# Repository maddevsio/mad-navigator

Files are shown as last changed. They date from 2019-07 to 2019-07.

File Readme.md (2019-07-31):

# Mad navigator

## Description

Mad navigator is simple compass-like device shows direction to predefined geo point.
This repository contains firmware source code and schematics for device. 



## Technologies and modules

- Microcontroller [STM32F100RBT6](https://www.st.com/content/ccc/resource/technical/document/reference_manual/a2/2d/02/4b/78/57/41/a3/CD00246267.pdf/files/CD00246267.pdf/jcr:content/translations/en.C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)
- LCD display [Nokia 5110](https://www.sparkfun.com/datasheets/LCD/Monochrome/Nokia5110.pdf)
- Accelerometer + gyroscope [MPU6050](https://store.invensense.com/datasheets/invensense/MPU-6050_DataSheet_V3%204.pdf)
- GPS receiver [Neo-6M](https://www.u-blox.com/sites/default/files/products/documents/NEO-6_DataSheet_%28GPS.G6-HW-09005%29.pdf)
- Magnetometer [QMC5883L](https://nettigo.pl/attachments/440)

## Prerequisites

- make
- arm-none-eabi-* (gcc, gdb, ar etc.)
- st-link utils

## Folder structure

root: Makefile, qtcreator project file (not neccessary to use it), LinkerScript

inc: All include files

src: All firmware source files

startup: Standard startup code

kicad_schema: Schematic

## How to run/debug

### RUN

Just use `make clean all program` . Make sure that your device connected via USB and you have all needed permissions.
You don't need to `make clean` every time. 

### DEBUG

1. `make clean all program`
2. run `st-util`. It will launch gdb server on localhost:4242. 
3. use arm-none-eabi-gdb

## Extended documentation

!TODO add link to medium

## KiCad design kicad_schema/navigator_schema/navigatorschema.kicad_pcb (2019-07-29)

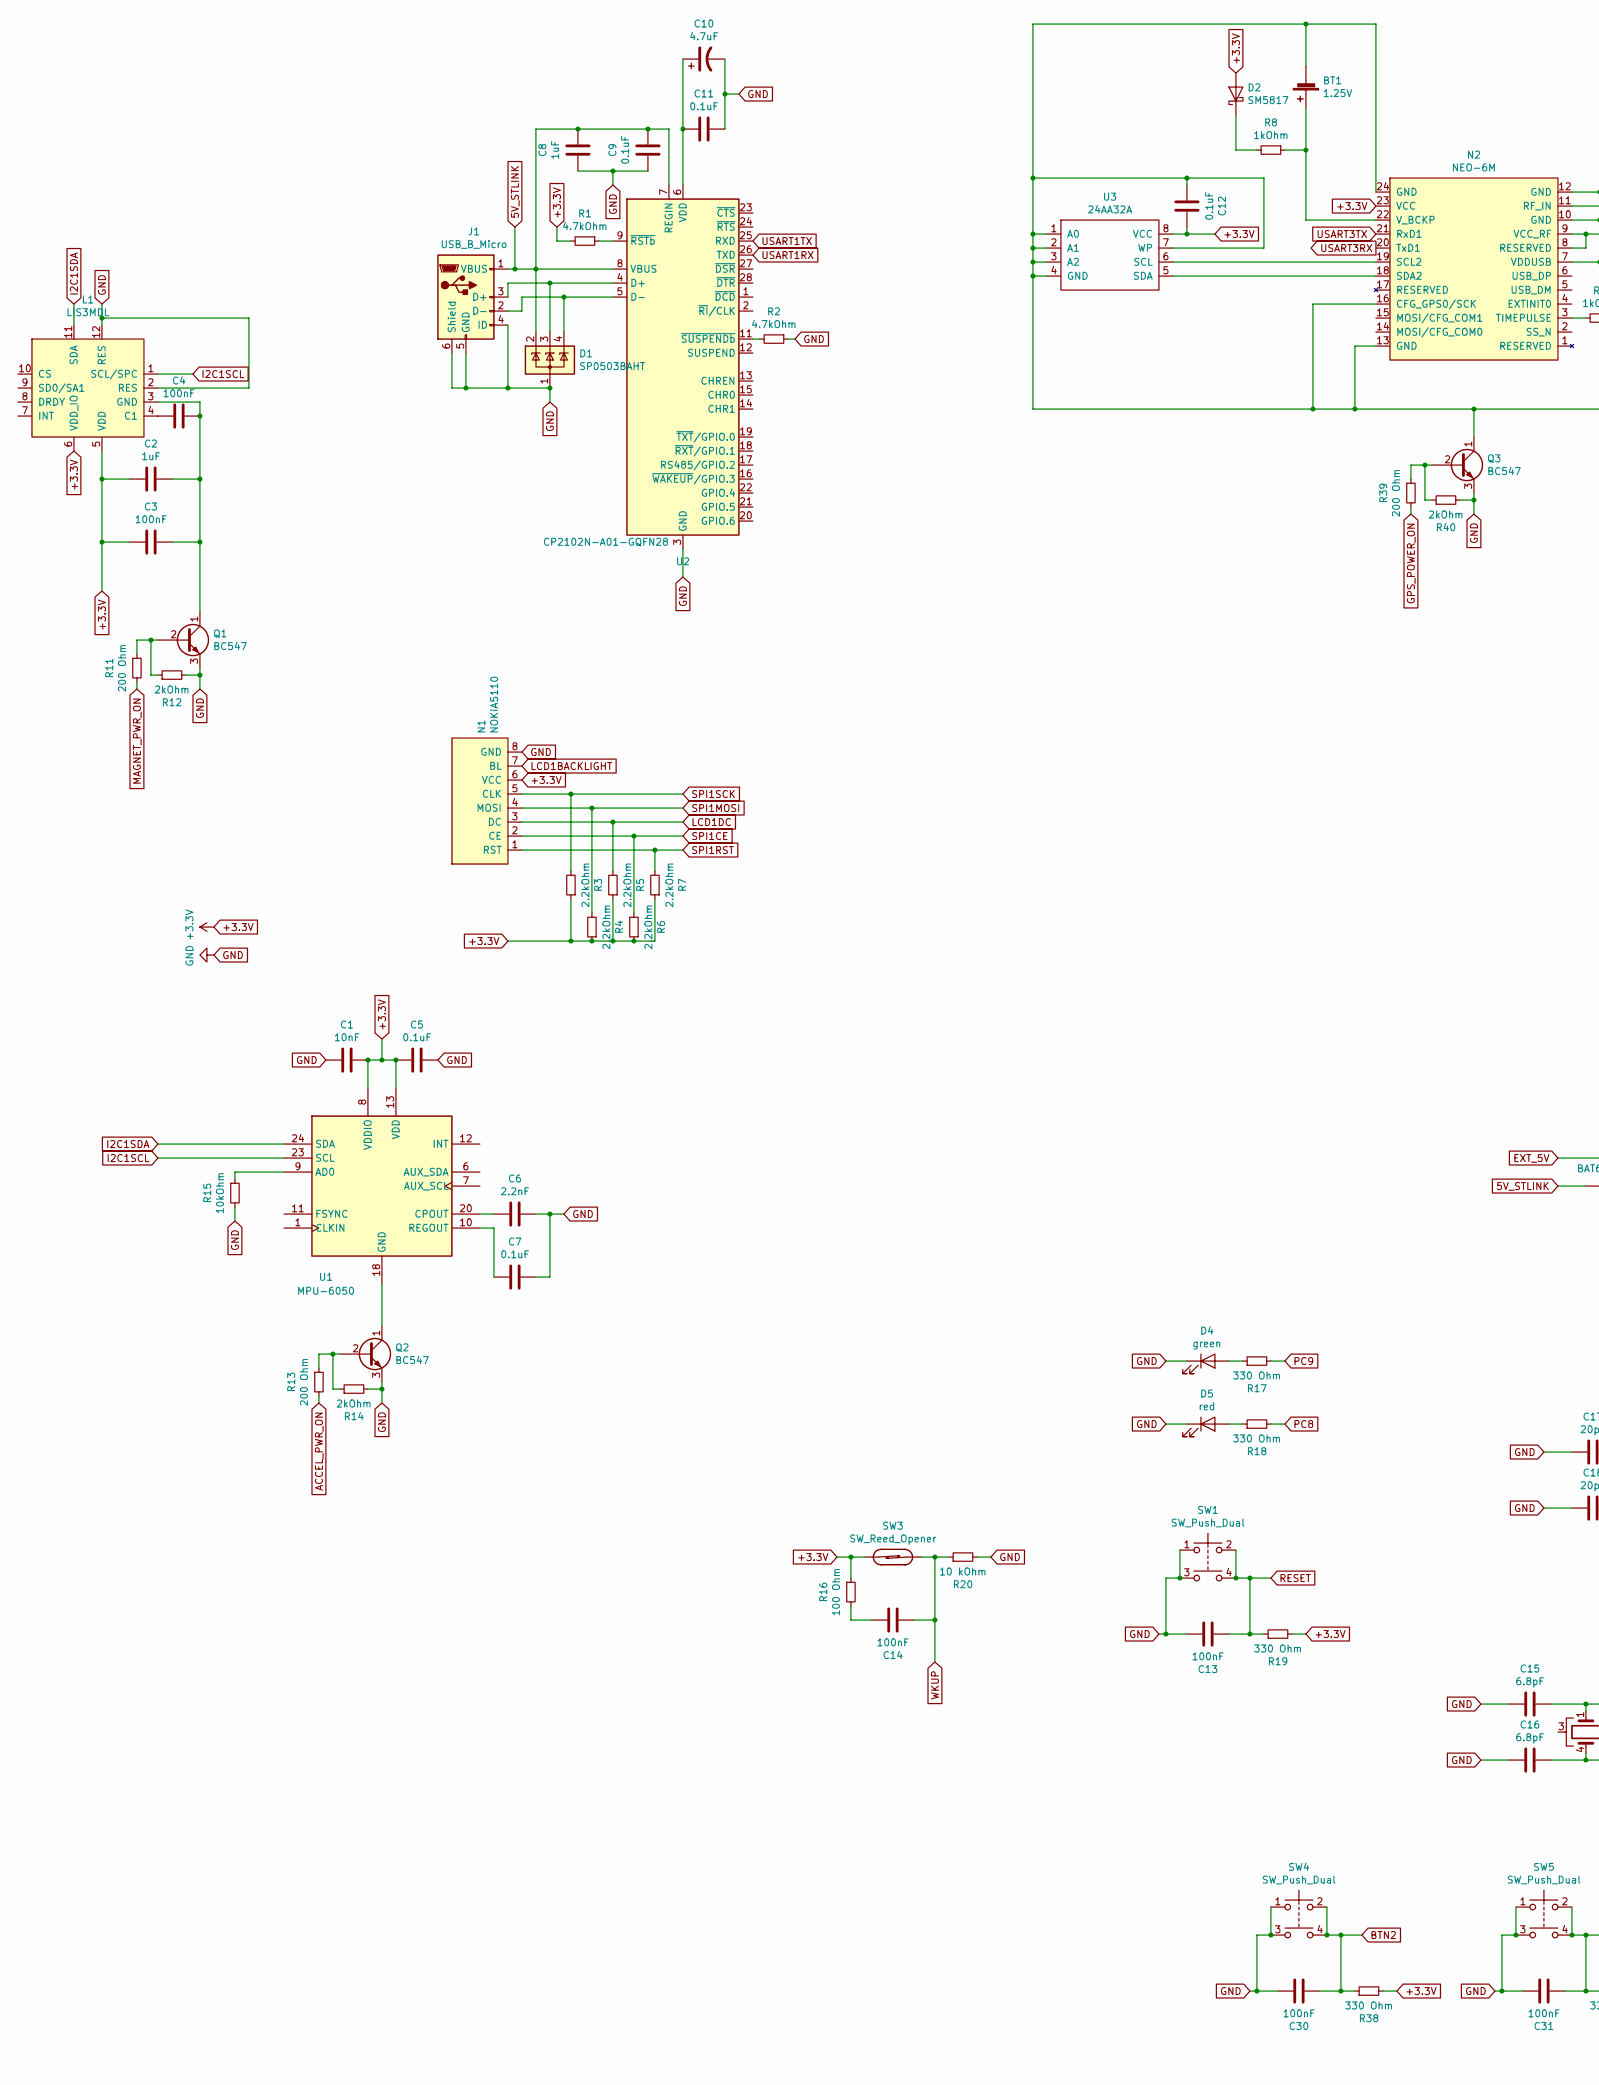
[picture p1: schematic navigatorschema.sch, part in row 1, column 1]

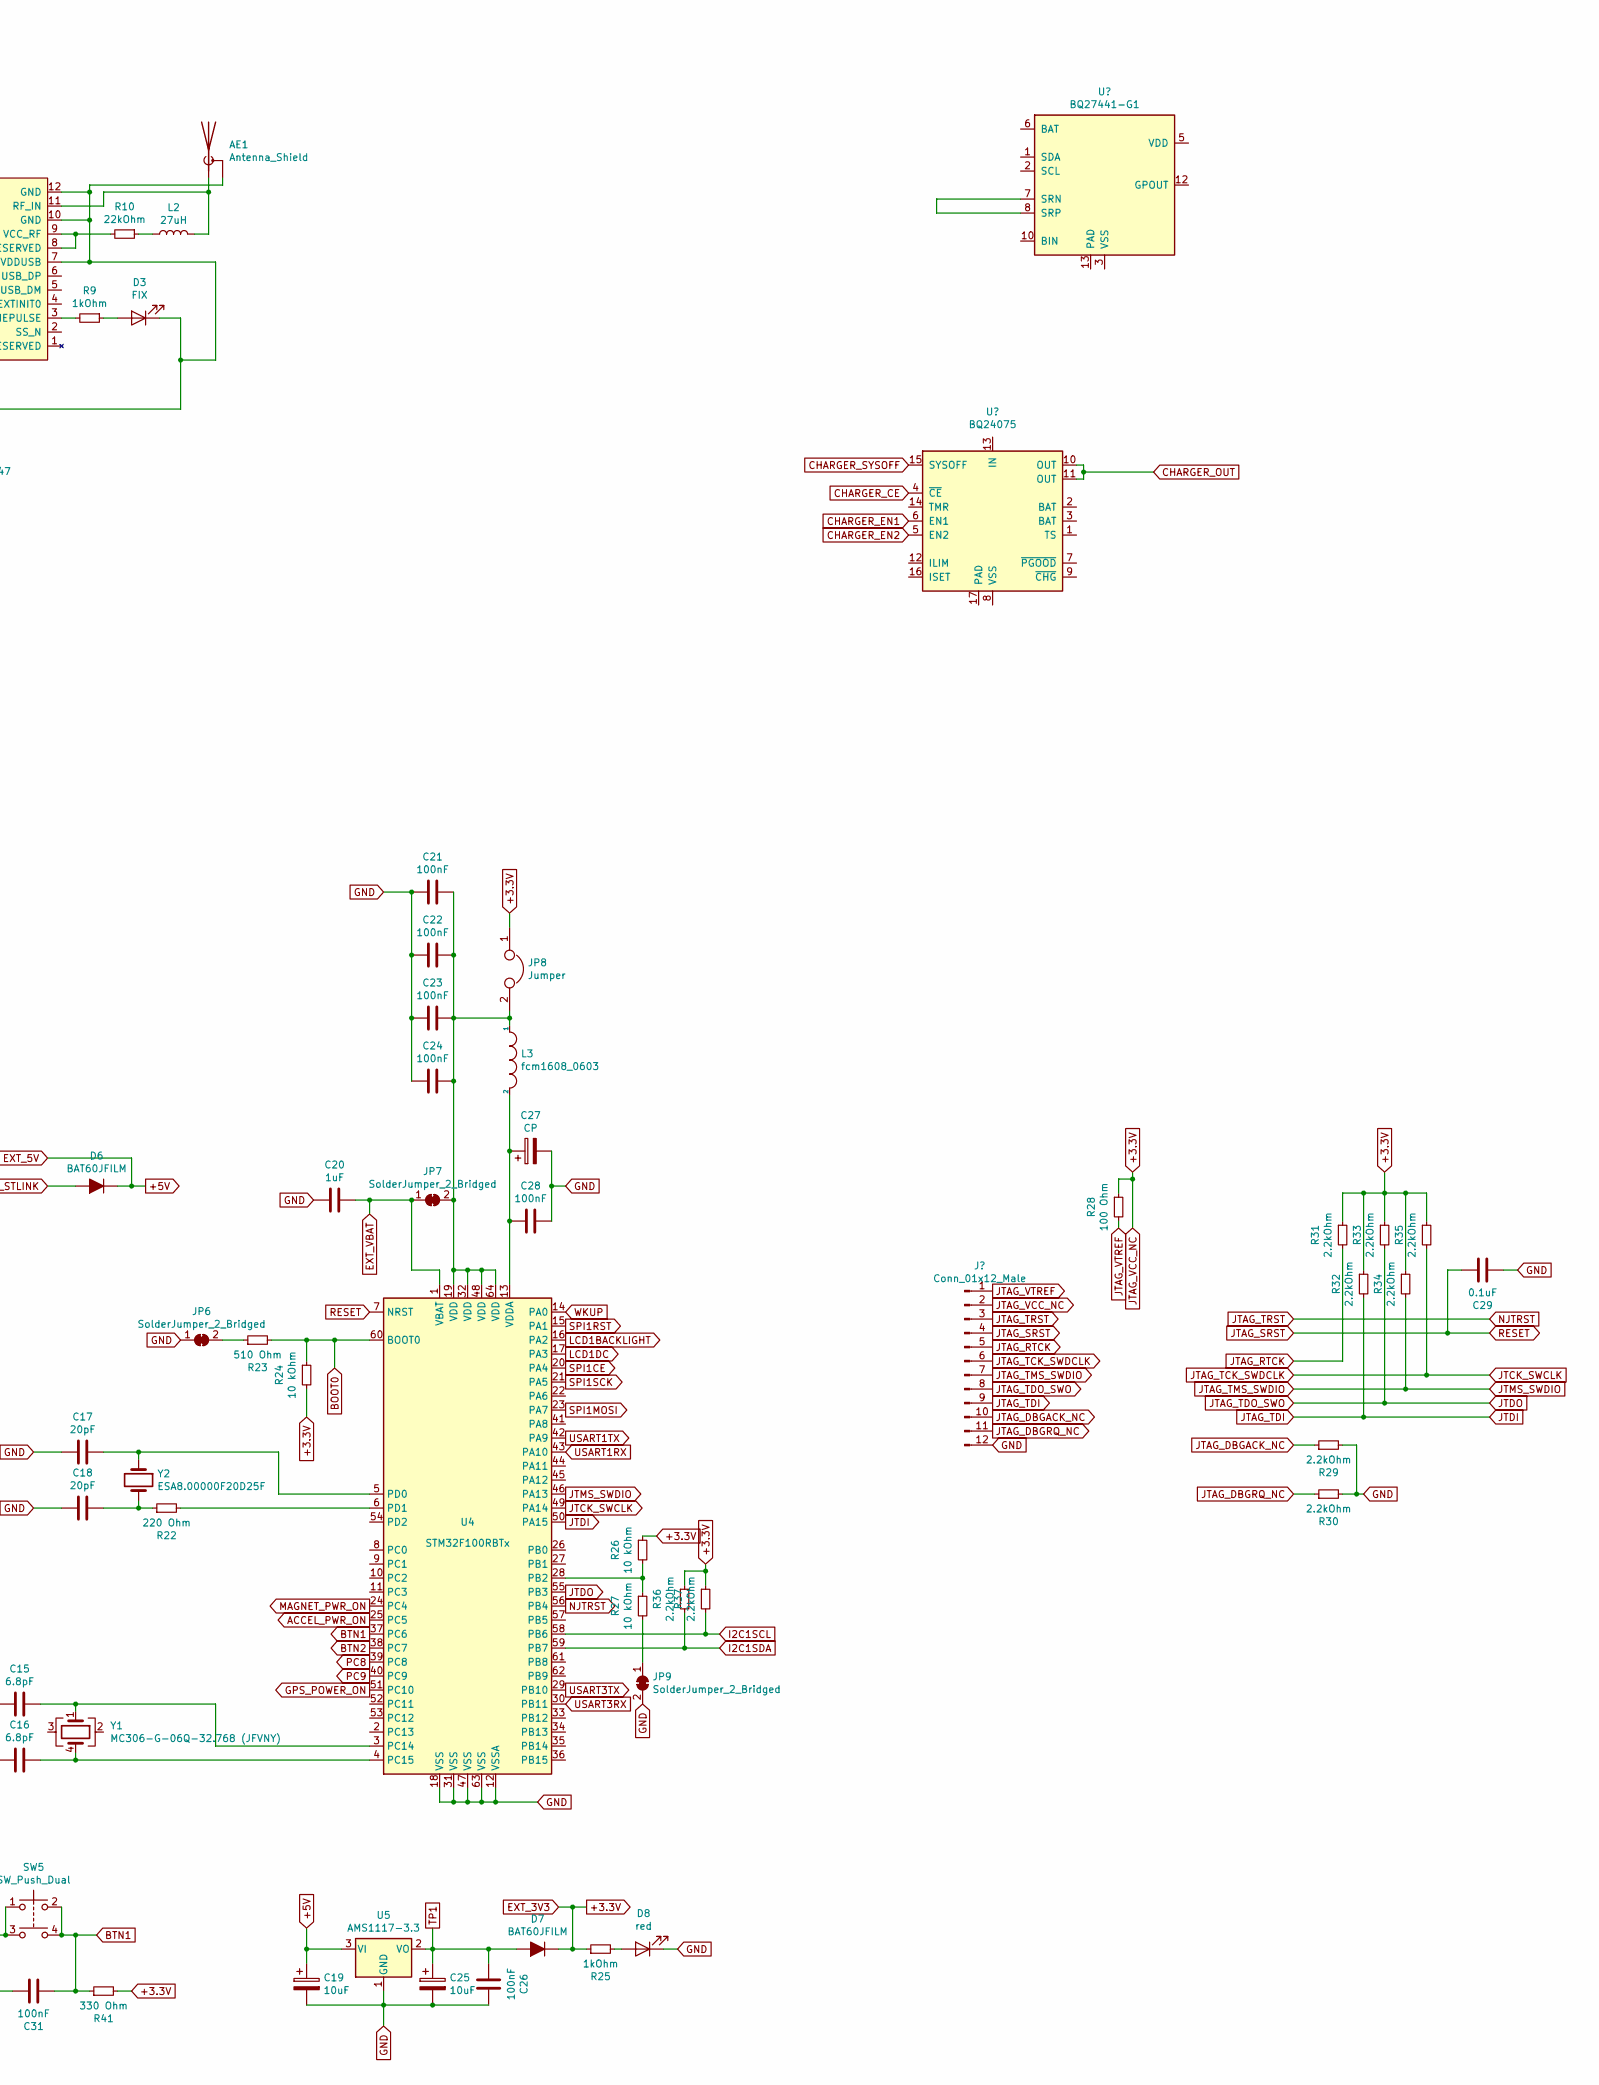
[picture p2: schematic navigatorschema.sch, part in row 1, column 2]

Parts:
AE1: Antenna_Shield; U.FL_Molex_MCRF_73412-0110_Vertical
BT1: 1.25V; BatteryHolder_Seiko_MS621F
C1: 10nF; C_01005_0402Metric
C2, C8, C20: 1uF; C_01005_0402Metric
C3, C4, C13, C14, C21, C22, C23, C24, C26, C28, C30, C31: 100nF; C_01005_0402Metric
C5, C7, C9, C11, C12, C29: 0.1uF; C_01005_0402Metric
C6: 2.2nF; C_01005_0402Metric
C10: 4.7uF; C_01005_0402Metric
C15, C16: 6.8pF; C_01005_0402Metric
C17, C18: 20pF; C_01005_0402Metric
C19, C25: 10uF; C_01005_0402Metric
C27: CP; C_01005_0402Metric
D1: SP0503BAHT; SOT-143
D2: SM5817; D_MELF
D3: FIX; LED_0201_0603Metric
D4: green; LED_0201_0603Metric
D5, D8: red; LED_0201_0603Metric
D6, D7: BAT60JFILM; D_SOD-323
J1: USB_B_Micro; USB_Micro-B_Molex-105017-0001
JP6, JP7, JP9: SolderJumper_2_Bridged; SolderJumper-2_P1.3mm_Bridged2Bar_Pad1.0x1.5mm
JP8: Jumper; PinHeader_1x02_P2.54mm_Vertical
L1: LIS3MDL; LGA-12_2x2mm_P0.5mm
L2: 27uH; L_6.3x6.3_H3
L3: fcm1608_0603; L_0603_1608Metric
N1: NOKIA5110; Nokia5110_blue
N2: NEO-6M; NEO6-M
Q1, Q2, Q3: BC547; SOT-23
R1, R2: 4.7kOhm; R_0603_1608Metric
R3, R4, R5, R6, R7, R29, R30, R31, R32, R33, R34, R35, R36, R37: 2.2kOhm; R_0603_1608Metric
R8, R9, R25: 1kOhm; R_0603_1608Metric
R10: 22kOhm; R_0603_1608Metric
R11, R13, R39: 200 Ohm; R_0603_1608Metric
R12, R14, R40: 2kOhm; R_0603_1608Metric
R15: 10kOhm; R_0603_1608Metric
R16, R28: 100 Ohm; R_0603_1608Metric
R17, R18, R19, R38, R41: 330 Ohm; R_0603_1608Metric
R20, R24, R26, R27: 10 kOhm; R_0603_1608Metric
R22: 220 Ohm; R_0603_1608Metric
R23: 510 Ohm; R_0603_1608Metric
SW1, SW4, SW5: SW_Push_Dual; SW_TH_Tactile_Omron_B3F-10xx
SW3: SW_Reed_Opener; SW_SPST_REED_CT05-XXXX-G1
U1: MPU-6050; InvenSense_QFN-24_4x4mm_P0.5mm
U2: CP2102N-A01-GQFN28; QFN-28-1EP_5x5mm_P0.5mm_EP3.35x3.35mm
U3: 24AA32A; SOIC-8_3.9x4.9mm_P1.27mm
U4: STM32F100RBTx; LQFP-64_10x10mm_P0.5mm
U5: AMS1117-3.3; SOT-223-3_TabPin2
Y1: MC306-G-06Q-32.768 (JFVNY); Crystal_SMD_0603-4Pin_6.0x3.5mm
Y2: ESA8.00000F20D25F; Crystal_SMD_2012-2Pin_2.0x1.2mm

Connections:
5V_STLINK: C8.1, C9.1, D1.2 (K), D6.2 (A), J1.1 (VBUS), U2.7 (REGIN), U2.8 (VBUS)
+3.3V: C1.1, C2.1, C3.1, C5.2, C12.1, D2.2 (A), D7.1 (K), JP8.1, L1.5 (VDD), L1.6 (VDD_IO), N1.6 (VCC), N2.23 (VCC), R1.2, R3.1, R4.1, R5.1, R6.1, R7.1, R16.1, R19.2, R24.2, R25.1, R26.1, R28.1, R31.1, R32.1, R33.1, R34.1, R35.1, R36.1, R37.1, R38.2, R41.2, SW3.1, U1.8 (VDDIO), U1.13 (VDD), U3.8 (VCC); also elsewhere on the board
+5V: C19.1, D6.1 (K), U5.3 (VI)
ACCEL_PWR_ON: R13.2, U4.25 (PC5)
BOOT0: R23.2, R24.1, U4.60 (BOOT0)
BTN1: C31.2, R41.1, SW5.2, SW5.4, U4.37 (PC6)
BTN2: C30.2, R38.1, SW4.2, SW4.4, U4.38 (PC7)
EXT_VBAT: C20.1, JP7.1 (A), U4.1 (VBAT)
GND: C1.2, C5.1, C6.2, C7.2, C8.2, C9.2, C10.2, C11.1, C13.1, C15.2, C16.2, C17.2, C18.2, C19.2, C20.2, C21.2, C22.2, C23.2, C24.2, C25.2, C26.1, C27.2, C28.1, C29.2, C30.1, C31.1, D1.1 (A), D4.1 (K), D5.1 (K), D8.1 (K), J1.4 (ID), J1.5 (GND), J1.6 (Shield), JP6.1 (A), JP9.2 (B), L1.2 (RES), L1.12 (RES), N1.8 (GND), Q1.3 (E), Q2.3 (E), Q3.3 (E), R2.1, R12.2, R14.2, R15.2, R20.2, R29.2, R30.2, R40.2, SW1.1, SW1.3, SW4.1, SW4.3, SW5.1, SW5.3, U2.3 (GND), U2.29 (GND), U4.12 (VSSA), U4.18 (VSS), U4.31 (VSS), U4.47 (VSS), U4.63 (VSS), U5.1 (GND); also elsewhere on the board
GPS_POWER_ON: R39.2, U4.51 (PC10)
I2C1SCL: L1.1 (SCL/SPC), R37.2, U1.23 (SCL), U4.58 (PB6)
I2C1SDA: L1.11 (SDA), R36.2, U1.24 (SDA), U4.59 (PB7)
JTCK_SWCLK: R35.2, U4.49 (PA14); also elsewhere on the board
JTDI: R32.2, U4.50 (PA15); also elsewhere on the board
JTDO: R33.2, U4.55 (PB3); also elsewhere on the board
JTMS_SWDIO: R34.2, U4.46 (PA13); also elsewhere on the board
LCD1BACKLIGHT: N1.7 (BL), U4.16 (PA2)
LCD1DC: N1.3 (DC), R5.2, U4.17 (PA3)
MAGNET_PWR_ON: R11.2, U4.24 (PC4)
NJTRST: U4.56 (PB4); also elsewhere on the board
unnamed: AE1.1 (A), L2.2, N2.11 (RF_IN)
unnamed: BT1.1 (+), N2.22 (V_BCKP), R8.1
unnamed: C2.2, C3.2, C4.2, L1.3 (GND), Q1.1 (C)
unnamed: C4.1, L1.4 (C1)
unnamed: C6.1, U1.20 (CPOUT)
unnamed: C7.1, U1.10 (REGOUT)
unnamed: C10.1, C11.2, U2.6 (VDD)
unnamed: C14.1, R16.2
unnamed: C15.1, U4.3 (PC14), Y1.1
unnamed: C16.1, U4.4 (PC15), Y1.4
unnamed: C17.1, U4.5 (PD0), Y2.1
unnamed: C18.1, R22.1, Y2.2
unnamed: C21.1, C22.1, C23.1, C24.1, JP7.2 (B), JP8.2, L3.1, U4.19 (VDD), U4.32 (VDD), U4.48 (VDD), U4.64 (VDD)
unnamed: C27.1, C28.2, L3.2, U4.13 (VDDA)
unnamed: D1.3 (K), J1.3 (D+), U2.4 (D+)
unnamed: D1.4 (K), J1.2 (D-), U2.5 (D-)
unnamed: D2.1 (K), R8.2
unnamed: D3.2 (A), R9.1
unnamed: D4.2 (A), R17.1
unnamed: D5.2 (A), R18.1
unnamed: D8.2 (A), R25.2
unnamed 41: R28.2; also elsewhere on the board
unnamed 42: R31.2; also elsewhere on the board
unnamed 43: R30.1; also elsewhere on the board
unnamed 44: R29.1; also elsewhere on the board
unnamed: JP6.2 (B), R23.1
unnamed: JP9.1 (A), R27.2
unnamed: L2.1, R10.1
unnamed: N2.3 (TIMEPULSE), R9.2
unnamed: N2.8 (RESERVED), N2.9 (VCC_RF), R10.2
unnamed: N2.18 (SDA2), U3.5 (SDA)
unnamed: N2.19 (SCL2), U3.6 (SCL)
unnamed: Q1.2 (B), R11.1, R12.1
unnamed: Q2.1 (C), U1.18 (GND)
unnamed: Q2.2 (B), R13.1, R14.1
unnamed: Q3.2 (B), R39.1, R40.1
unnamed: R1.1, U2.9 (~RSTb)
unnamed: R2.2, U2.11 (~SUSPENDb)
unnamed: R15.1, U1.9 (AD0)
unnamed: R22.2, U4.6 (PD1)
unnamed: R26.2, R27.1, U4.28 (PB2)
PC8: R18.2, U4.39 (PC8)
PC9: R17.2, U4.40 (PC9)
RESET: C13.2, C29.1, R19.1, SW1.2, SW1.4, U4.7 (NRST); also elsewhere on the board
SPI1CE: N1.2 (CE), R6.2, U4.20 (PA4)
SPI1MOSI: N1.4 (MOSI), R4.2, U4.23 (PA7)
SPI1RST: N1.1 (RST), R7.2, U4.15 (PA1)
SPI1SCK: N1.5 (CLK), R3.2, U4.21 (PA5)
TP1: C25.1, C26.2, D7.2 (A), U5.2 (VO)
USART1RX: U2.26 (TXD), U4.43 (PA10)
USART1TX: U2.25 (RXD), U4.42 (PA9)
USART3RX: N2.20 (TxD1), U4.30 (PB11)
USART3TX: N2.21 (RxD1), U4.29 (PB10)
WKUP: C14.2, R20.1, SW3.2, U4.14 (PA0); also elsewhere on the board

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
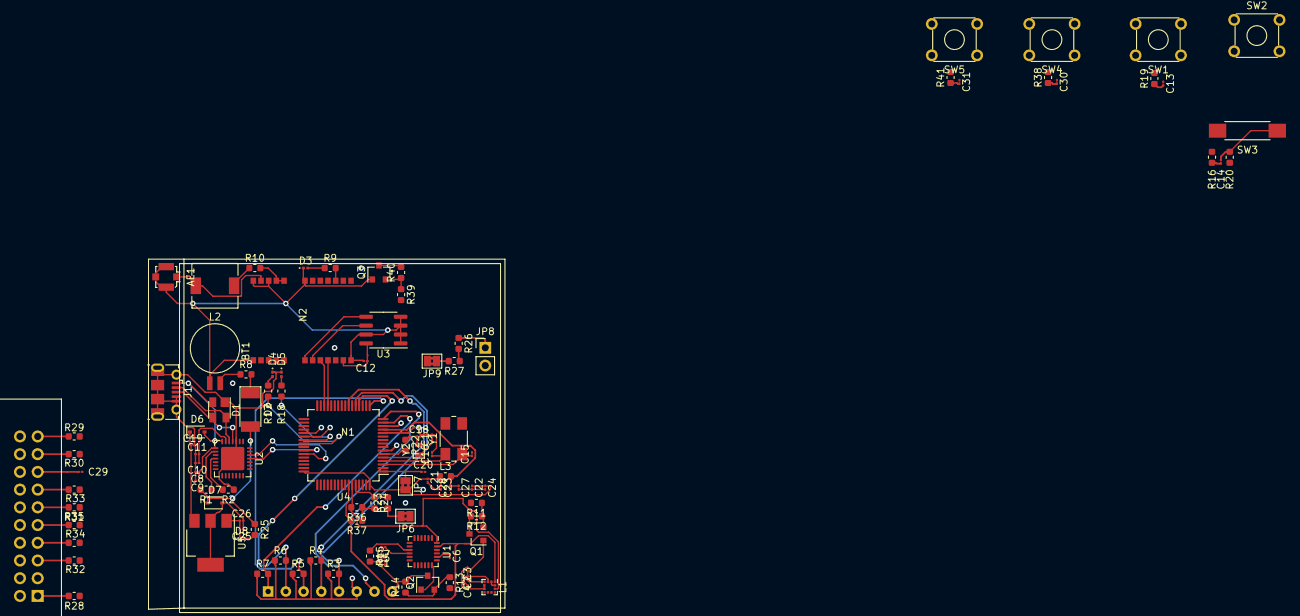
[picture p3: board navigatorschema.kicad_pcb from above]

Board: 2 copper layers, 107 parts (0 on the bottom side), 75 nets.

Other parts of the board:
J4: Conn_ARM_JTAG_SWD_20; IDC-Header_2x10_P2.54mm_Vertical
SW2: SW_Push_Dual; SW_TH_Tactile_Omron_B3F-10xx

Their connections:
+3.3V: J4.2, SW2.1, SW2.3; also elsewhere on the board
GND: J4.4, J4.6, J4.8, J4.10, J4.12, J4.14, J4.16, J4.18, J4.20; also elsewhere on the board
JTCK_SWCLK: J4.9; also elsewhere on the board
JTDI: J4.5; also elsewhere on the board
JTDO: J4.13; also elsewhere on the board
JTMS_SWDIO: J4.7; also elsewhere on the board
NJTRST: J4.3; also elsewhere on the board
unnamed 41: J4.1; also elsewhere on the board
unnamed 42: J4.11; also elsewhere on the board
unnamed 43: J4.17; also elsewhere on the board
unnamed 44: J4.19; also elsewhere on the board
RESET: J4.15; also elsewhere on the board
WKUP: SW2.2, SW2.4; also elsewhere on the board

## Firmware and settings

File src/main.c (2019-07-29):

/**
 ******************************************************************************
 * @file    main.c
 * @author  Ac6
 * @version V1.0
 * @date    01-December-2013
 * @brief   Default main function.
 ******************************************************************************
 */

#include <math.h>
#include <stdlib.h>
#include <stdint.h>
#include <stdio.h>

#include "stm32f10x.h"
#include "stm32vldiscovery_utils.h"
#include "stm32f10x_rcc.h"

#include "accelerometer/mpu6050/mpu6050_i2c.h"
#include "gps/neo6m.h"
#include "display/display.h"
#include "time/kov_time.h"
#include "power/power.h"
#include "time/kov_time.h"
#include "flash/settings.h"

#include "commons/commons.h"
#include "commons/bearing.h"
#include "commons/madgwick.h"
#include "commons/magnetic.h"
#include "commons/quaternion.h"
#include "commons/vector3d.h"
#include "i2c1/i2c1.h"

#include "magnetometer/lis3mdl/lis3mdl_i2c.h"
#include "magnetometer/hmc5883/hmc5883.h"
#include "magnetometer/qmc5883l/qmc5883l.h"

static const vector3d_t m_vec_ix = {.x = 1.0f, .y = 0.0f, .z = 0.0f};
static const vector3d_t m_vec_iy = {.x = 0.0f, .y = 1.0f, .z = 0.0f};
static const vector3d_t m_vec_iz = {.x = 0.0f, .y = 0.0f, .z = 1.0f};

static AHRSData m_ahrs;
static mpu6050_raw_data_t m_imuRaw;
static qmc5883l_raw_data_t m_magRaw;

static quaternion_t m_dst_q;
static quaternion_t m_magnetic_decl_q;

static vector3d_t m_dst_vecX;
static vector3d_t m_dst_vecY;

static volatile float m_declination = 0.0f;
static volatile float m_bearing = 0.0f;

static volatile float m_currentAngleX = 0.0f;
static volatile float m_currentAngleY = 0.0f;

static volatile uint16_t m_seconds_from_start = 0;
static volatile bool m_need_update_time = false;

///////////////////////////////////////////////////////
///////////////////////////////////////////////////////
///////////////////////////////////////////////////////

//!todo move to flash!
static const float m_dst_lat = 21.422513f;
static const float m_dst_lon = 39.826197f;
static const uint16_t m_work_time_sec = 60;
static uint32_t m_time_offset = 3600 * 6; //+6GMT

#define MagXMin 6010
#define MagXMax 6252
#define MagYMin 1175
#define MagYMax 4282
#define MagZMin 1895
#define MagZMax 6585

#define MagXBias ((MagXMin + MagXMax) / 2)
#define MagYBias ((MagYMin + MagYMax) / 2)
#define MagZBias ((MagZMin + MagZMax) / 2)

#define MagXAvgDelta ((MagXMax - MagXMin) / 2.0f)
#define MagYAvgDelta ((MagYMax - MagYMin) / 2.0f)
#define MagZAvgDelta ((MagZMax - MagZMin) / 2.0f)

#define MagAvgDelta ((MagXAvgDelta + MagYAvgDelta + MagZAvgDelta) / 3.0f)

#define MagXScale (MagAvgDelta / MagXAvgDelta)
#define MagYScale (MagAvgDelta / MagYAvgDelta)
#define MagZScale (MagAvgDelta / MagZAvgDelta)

#define imu_calibration_steps 3000
#define gyro_250_gain 131.0f
static int16_t m_gx_bias = -656;
static int16_t m_gy_bias = -368;
static int16_t m_gz_bias = 78;

static int16_t m_ax_bias = 0;
static int16_t m_ay_bias = 0;
static int16_t m_az_bias = 0;

static void gyrAccCalibrationFinishedMsg(void);

static void correctDstDirection(void);
static void updateCurrentAngle(void);
static void correctBearingAndDeclination(float alt, float lat, float lon, float year);
static void readAHRSRaw(void);
static void readAHRSData(void);
static void calculateOrientation(void);
static void readGPS(void);
static void initTIM2(void);
static void printCurrentDateTime(const kov_date_t *d, const kov_time_t *t);

///////////////////////////////////////////////////////
///////////////////////////////////////////////////////

void correctDstDirection(void) {
  m_dst_q = quaternion_new_vec(&m_vec_iz, m_bearing * deg2rad_coeff);
  m_dst_vecX = quaternion_transform_vec(&m_dst_q, &m_vec_ix);
  m_dst_vecY = quaternion_transform_vec(&m_dst_q, &m_vec_iy);
}
///////////////////////////////////////////////////////

void updateCurrentAngle(void) {
  quaternion_t q_curr = quaternion_new_wxyz(q0, q1, q2, q3);
  vector3d_t currVecX = quaternion_transform_vec(&q_curr, &m_vec_ix);
  vector3d_t currVecY = quaternion_transform_vec(&q_curr, &m_vec_iy);

  float angleX = vector_flatCos(&currVecX, &m_dst_vecX);
  float signX = vector_rotationSign(&currVecX, &m_dst_vecX);
  angleX = acosf(angleX);
  m_currentAngleX = signX * rad2deg_coeff * angleX;

  float angleY = vector_flatCos(&currVecY, &m_dst_vecY);
  float signY = vector_rotationSign(&currVecY, &m_dst_vecY);
  angleY = acosf(angleY);
  m_currentAngleY = signY * rad2deg_coeff * angleY;
}
///////////////////////////////////////////////////////

void correctBearingAndDeclination(float alt, float lat,
                                  float lon, float year) {
  float declination = 0.0f;
  magnetic_calculate(alt / 1000.f, lat, lon,
                     year, &declination,
                     NULL, NULL, NULL);
  m_declination = declination;
  m_bearing = initialBearing(lat, lon, m_dst_lat, m_dst_lon);
  m_bearing = 360.0f - fmodf(m_bearing + 360.0f, 360.0f);
  m_magnetic_decl_q = quaternion_new_vec(&m_vec_iz, m_declination * deg2rad_coeff);
}
///////////////////////////////////////////////////////

void readAHRSRaw(void) {
  mpu6050ReadSync(&m_imuRaw);
  mpu6050FixData(&m_imuRaw);

  qmc5883lReadHeadingSync(&m_magRaw);
  qmc5883lFixRawData(&m_magRaw);
}
///////////////////////////////////////////////////////

void readAHRSData(void) {
  float currentMagGain = qmc5883l_gain();
  readAHRSRaw();
  //we can use raw data from accelerometer because
  //it's normalized inside Madgwick filter
  m_ahrs.imu.acc.ax = (float)m_imuRaw.data.ax;
  m_ahrs.imu.acc.ay = (float)m_imuRaw.data.ay;
  m_ahrs.imu.acc.az = (float)m_imuRaw.data.az;

  //but we have to use radian/sec as unit for gyroscope
  m_imuRaw.data.gx -= m_gx_bias;
  m_imuRaw.data.gy -= m_gy_bias;
  m_imuRaw.data.gz -= m_gz_bias;

  m_ahrs.imu.gyro.gx = (float)(m_imuRaw.data.gx / gyro_250_gain) * deg2rad_coeff;
  m_ahrs.imu.gyro.gy = (float)(m_imuRaw.data.gy / gyro_250_gain) * deg2rad_coeff;
  m_ahrs.imu.gyro.gz = (float)(m_imuRaw.data.gz / gyro_250_gain) * deg2rad_coeff;

  //remove hard iron distortion + use ellipse rescaling.
  //https://github.com/kriswiner/MPU6050/wiki/Simple-and-Effective-Magnetometer-Calibration
  //!todo soft iron distortion compensation with matrix
  m_ahrs.mag.mx = (float)(m_magRaw.data.mx - MagXBias) * MagXScale;
  m_ahrs.mag.my = (float)(m_magRaw.data.my - MagYBias) * MagYScale;
  m_ahrs.mag.mz = (float)(m_magRaw.data.mz - MagZBias) * MagZScale;
  m_ahrs.mag.mx /= currentMagGain;
  m_ahrs.mag.my /= currentMagGain;
  m_ahrs.mag.mz /= currentMagGain;

  //to microgauss
  m_ahrs.mag.mx *= 1000000.f;
  m_ahrs.mag.my *= 1000000.f;
  m_ahrs.mag.mz *= 1000000.f;
}
///////////////////////////////////////////////////////

void calculateOrientation(void) {
  vector3d_t magv = vector_new(m_ahrs.mag.mx, m_ahrs.mag.my, m_ahrs.mag.mz);
  vector3d_t magvc = quaternion_transform_vec(&m_magnetic_decl_q, &magv);
  readAHRSData();
  //be careful here. see  directions of magnetometer and acclerometer with gyroscope
  MadgwickAHRSupdate(m_ahrs.imu.gyro.gx, m_ahrs.imu.gyro.gy, m_ahrs.imu.gyro.gz,
                     m_ahrs.imu.acc.ax, m_ahrs.imu.acc.ay, m_ahrs.imu.acc.az,
                     magvc.x, magvc.y, magvc.z);
  updateCurrentAngle();

  static char buff[16] = {0};
  quaternion_t q = quaternion_new_wxyz(q0, q1, q2, q3);
  display->printText(0, 0, "x:");
  display->printText(2, 0, ftoa(m_currentAngleX, buff, 5));
  display->printText(0, 1, "y:");
  display->printText(2, 1, ftoa(quaternion_yaw(&q) * rad2deg_coeff, buff, 5));
}
///////////////////////////////////////////////////////

#define TS_CORRECTION_THRESHOLD_SEC 5
void readGPS(void) {
  if (!neo6m_needParseCurrentBuff)
    return;
  neo6m_needParseCurrentBuff = false;
  bool valid = false;
  neo6m_data_t d = neo6m_parseCurrentBuff(&valid);
  if (!valid)
    return;

  neo6m_interrupts(false);
  kov_timestamp_t ts_gps = nmea_gettime(&d.date, &d.time);
  kov_timestamp_t ts_loc = RTC_CurrentTimestamp();
  ts_loc -= m_time_offset;

  uint32_t ts_diff = ts_gps >= ts_loc ? ts_gps - ts_loc : ts_loc - ts_gps;
  if (ts_diff > TS_CORRECTION_THRESHOLD_SEC)
    RTC_Adjust(ts_gps + m_time_offset);

  float year = d.date.year + (float)d.date.month / 12.0f;

  /*todo get current altitude from GPS*/
  correctBearingAndDeclination(0.0f, d.latitude, d.longitude, year);
  correctDstDirection();
  neo6m_power(false); //save energy, turn GPS OFF! :)
}
///////////////////////////////////////////////////////

void initTIM2(void) {
  /*configure tim2*/
  RCC_APB1PeriphClockCmd(RCC_APB1Periph_TIM2, ENABLE);
  TIM_TimeBaseInitTypeDef tim2_cfg;

  tim2_cfg.TIM_ClockDivision = TIM_CKD_DIV1; //24 000 000
  tim2_cfg.TIM_Prescaler = 23999; //1KHz
  tim2_cfg.TIM_CounterMode = TIM_CounterMode_Up;
  tim2_cfg.TIM_Period = 999; // 1.0 second!
  tim2_cfg.TIM_RepetitionCounter = 0;

  TIM_TimeBaseInit(TIM2, &tim2_cfg);
  TIM_Cmd(TIM2, ENABLE);

  /*configure NVIC*/
  NVIC_InitTypeDef nvicStructure;
  nvicStructure.NVIC_IRQChannel = TIM2_IRQn;
  nvicStructure.NVIC_IRQChannelPreemptionPriority = 1;
  nvicStructure.NVIC_IRQChannelSubPriority = 0;
  nvicStructure.NVIC_IRQChannelCmd = ENABLE;
  NVIC_Init(&nvicStructure);

  TIM_ITConfig(TIM2, TIM_IT_Update, ENABLE);
}
///////////////////////////////////////////////////////

void TIM2_IRQHandler() {
  if (TIM2->SR & TIM_IT_Update) {
    TIM_ClearITPendingBit(TIM2, TIM_IT_Update);
    ++m_seconds_from_start;
    m_need_update_time = true;
  }
}
///////////////////////////////////////////////////////

void printCurrentDateTime(const kov_date_t *d, const kov_time_t *t) {
  display->printText(0, 0, RTC_DateTimeStr(d, t));
}
///////////////////////////////////////////////////////

typedef enum operation_mode {
  OP_NORMAL = 0,
  OP_ACC_CALIBRATION = 1,
  OP_GYR_CALIBRATION = 2,
  OP_MAG_CALIBRATION = 3
} operation_mode_t;

static operation_mode_t m_mode = OP_GYR_CALIBRATION;

static void op_normal(void);
static void op_acc_calibration(void);
static void op_gyr_calibration(void);
static void op_mag_calibration(void);
static void magnetometerCalibration(int16_t mx, int16_t my, int16_t mz);
static void gyroscopeCalibration(int16_t gx, int16_t gy, int16_t gz);
static void accelerometerCalibration(int16_t ax, int16_t ay, int16_t az);

void gyrAccCalibrationFinishedMsg(void) {
  display->clear();
  display->printText(0, 0, "Calibration");
  display->printText(0, 1, "is finished");
  display->printText(0, 2, "Wait!");
  display->syncAll();
  waitTicks(12000000); //~0.5 sec
  display->clear();
}
///////////////////////////////////////////////////////

void magnetometerCalibration(int16_t mx, int16_t my, int16_t mz) {
  static char buff[32] = {0};
  static volatile int16_t m_magX_min = INT16_MAX, m_magX_max = INT16_MIN;
  static volatile int16_t m_magY_min = INT16_MAX, m_magY_max = INT16_MIN;
  static volatile int16_t m_magZ_min = INT16_MAX, m_magZ_max = INT16_MIN;

  if (mx < m_magX_min)
    m_magX_min = mx;
  if (mx > m_magX_max)
    m_magX_max = mx;

  if (my < m_magY_min)
    m_magY_min = my;
  if (my > m_magY_max)
    m_magY_max = my;

  if (mz < m_magZ_min)
    m_magZ_min = mz;
  if (mz > m_magZ_max)
    m_magZ_max = mz;

  display->printText(0, 0, "x0:");
  display->printText(3, 0, int32ToStr(buff, m_magX_min, sizeof(buff)));
  display->printText(0, 1, "x1:");
  display->printText(3, 1, int32ToStr(buff, m_magX_max, sizeof(buff)));
  display->printText(0, 2, "y0:");
  display->printText(3, 2, int32ToStr(buff, m_magY_min, sizeof(buff)));
  display->printText(0, 3, "y1:");
  display->printText(3, 3, int32ToStr(buff, m_magY_max, sizeof(buff)));
  display->printText(0, 4, "z0:");
  display->printText(3, 4, int32ToStr(buff, m_magZ_min, sizeof(buff)));
  display->printText(0, 5, "z1:");
  display->printText(3, 5, int32ToStr(buff, m_magZ_max, sizeof(buff)));
  display->syncAll();
}
///////////////////////////////////////////////////////

void gyroscopeCalibration(int16_t gx, int16_t gy, int16_t gz) {
  static float gx_mean = 0.0f, gy_mean = 0.0f, gz_mean = 0.0f;
  static uint16_t count = imu_calibration_steps;
  if (count == 0) {
    gx_mean /= (float)imu_calibration_steps;
    gy_mean /= (float)imu_calibration_steps;
    gz_mean /= (float)imu_calibration_steps;
    m_gx_bias = (int16_t) (ceilf(gx_mean));
    m_gy_bias = (int16_t) (ceilf(gy_mean));
    m_gz_bias = (int16_t) (ceilf(gz_mean));
    gyrAccCalibrationFinishedMsg();
    m_mode = OP_NORMAL;
  }
  gx_mean += (float)gx;
  gy_mean += (float)gy;
  gz_mean += (float)gz;
  --count;
}
///////////////////////////////////////////////////////

void accelerometerCalibration(int16_t ax, int16_t ay, int16_t az) {
  static float ax_mean = 0.0f, ay_mean = 0.0f, az_mean = 0.0f;
  static uint16_t count = imu_calibration_steps;
  if (count == 0) {
    ax_mean /= (float)imu_calibration_steps;
    ay_mean /= (float)imu_calibration_steps;
    az_mean /= (float)imu_calibration_steps;
    m_ax_bias = (int16_t) (ceilf(ax_mean));
    m_ay_bias = (int16_t) (ceilf(ay_mean));
    m_az_bias = (int16_t) (ceilf(az_mean));
    gyrAccCalibrationFinishedMsg();
    m_mode = OP_NORMAL;
  }
  ax_mean += (float)ax;
  ay_mean += (float)ay;
  az_mean += (float)az;
  --count;
}
///////////////////////////////////////////////////////

void op_normal(void) {
  static float deltaAngleX = 0.0f;
  static float prevAngleX = 0.0f;
#define deltaAngleThreshold 1.5f

  if (m_need_update_time) {
    kov_date_t d;
    kov_time_t t;
    kov_timestamp_t ts = RTC_CurrentTimestamp();
    RTC_GetDateTime(ts, &d, &t);
    printCurrentDateTime(&d, &t);
    m_need_update_time = false;
  }

  readGPS();
  calculateOrientation();

  deltaAngleX = m_currentAngleX - prevAngleX;
  if (deltaAngleX > deltaAngleThreshold || deltaAngleX < -deltaAngleThreshold) { //abs(dx) < da
    drawCircleFromBuffer(42, 27, true);
    drawArrow(42, 27, deg2rad_coeff * (-m_currentAngleX), false);
    prevAngleX = m_currentAngleX;
  }
  display->syncAll();
  if(m_seconds_from_start > m_work_time_sec) {
//    goToSleepMode();
  }
}
///////////////////////////////////////////////////////

void op_acc_calibration(void) {
  mpu6050ReadSync(&m_imuRaw);
  mpu6050FixData(&m_imuRaw);
  accelerometerCalibration(m_imuRaw.data.ax, m_imuRaw.data.ay, m_imuRaw.data.az);
}
///////////////////////////////////////////////////////

void op_gyr_calibration(void) {
  mpu6050ReadSync(&m_imuRaw);
  mpu6050FixData(&m_imuRaw);
  gyroscopeCalibration(m_imuRaw.data.gx, m_imuRaw.data.gy, m_imuRaw.data.gz);
}
///////////////////////////////////////////////////////

void op_mag_calibration(void) {
  qmc5883lReadHeadingSync(&m_magRaw);
  qmc5883lFixRawData(&m_magRaw);
  magnetometerCalibration(m_magRaw.data.mx, m_magRaw.data.my, m_magRaw.data.mz);
}
///////////////////////////////////////////////////////

static uint32_t m_pvd_current = PWR_PVDLevel_2V9 + 0x20;
static void pvd_ctrl(void) {
  if (PWR->CSR & PWR_CSR_PVDO) {
    if (m_pvd_current == PWR_PVDLevel_2V2) {
      //!todo some message that need to charge
      return;
    }

    m_pvd_current -= 0x20; //WARNING!
    PWR_PVDLevelConfig(m_pvd_current);
    return;
  }
}
///////////////////////////////////////////////////////

static void pvd_print(void) {
  float percent = (float)m_pvd_current / (float)(PWR_PVDLevel_2V9 + 0x20);

  /*print empty rectangle*/
#define left 76
#define right 83
#define top 10
#define bottom 47
#define full_height (bottom - top)

  drawLine(left, top, left, bottom, true); //left
  drawLine(left, top, right, top, true); //top
  drawLine(right, top, right, bottom, true); //right
  drawLine(left, bottom, right, bottom, true);

  /*print full rectangle by percentage*/
  int16_t ch = (int16_t)(percent * full_height);
  for (int16_t x = left+1; x < right; ++x) {
    drawLine(x, bottom, x, bottom - ch, true);
  }
  display->syncAll();
}
///////////////////////////////////////////////////////

int main(void) {
  /* Enable PWR and BKP clock */
  RCC_APB1PeriphClockCmd(RCC_APB1Periph_PWR, ENABLE);
  PWR_PVDLevelConfig(m_pvd_current);
  PWR_PVDCmd(ENABLE);

  MadgwickInit(130.0f, 0.4f);
//  initDWT();

  //todo make some indication in case of some of modules doesn't work
  //if display doesn't work - blink with diod
  //if any another module doesn't work - message on display and exit.
  display = initDisplay();
  display->setBacklight(true);
  display->clear();

  i2c1_init();
  display->printText(0, 0, "I2C1 init!");
  display->syncAll();

  mpu6050_pin_config();
  mpu6050_power(true);
  waitTicks(50000);
  mpu6050_init();
  display->printText(0, 1, "MPU6050 init!");
  display->syncAll();

  qmc5883l_pin_config();
  qmc5883l_power(true);
  waitTicks(50000);
  qmc5883l_init();
  display->printText(0, 2, "QMC5883 init!");
  display->syncAll();

  neo6m_init();
  neo6m_power(true);
  waitTicks(50000);
  neo6m_interrupts(true);
  display->printText(0, 3, "USART3 init!");
  display->syncAll();

  RTC_Init();
  display->printText(0, 4, "RTC init!");
  display->syncAll();

  initWakeup();
  display->printText(0, 5, "WAKEUP init!");
  display->syncAll();

  //!todo remove after tests , read from FLASH!
#define bish_lat 42.879965f
#define bish_lon 74.617977f

#define mos_lat 55.752124f
#define mos_lon 37.619779f

  correctBearingAndDeclination(0.0f, bish_lat, bish_lon, 2019.5);
  correctDstDirection();
  //!!!!!!!!!!!!!!!!!!!!

  initTIM2();

  display->syncAll();
  display->clear();
  calcCircleBuffer(21);

  pvd_ctrl(); //todo move
  pvd_print();

  while (1) {
    switch (m_mode) {
      case OP_NORMAL:
        op_normal();
        break;
      case OP_ACC_CALIBRATION:
        op_acc_calibration();
        break;
      case OP_GYR_CALIBRATION:
        op_gyr_calibration();
        break;
      case OP_MAG_CALIBRATION:
        op_mag_calibration();
        break;
    }
  }
//  return 0;
}

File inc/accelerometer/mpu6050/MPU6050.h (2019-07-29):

//MPU6050 I2C library for ARM STM32F103xx Microcontrollers - Main header file 
//Has bit, byte and buffer I2C R/W functions
// 23/05/2012 by Harinadha Reddy Chintalapalli <harinath.ec@gmail.com>
// Changelog:
//     2012-05-23 - initial release. Thanks to Jeff Rowberg <jeff@rowberg.net> for his AVR/Arduino
//                  based development which inspired me & taken as reference to develop this.
/* ============================================================================================
 MPU6050 device I2C library code for ARM STM32F103xx is placed under the MIT license
 Copyright (c) 2012 Harinadha Reddy Chintalapalli

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
 THE SOFTWARE IS PROVIDED "AS IS", WITHOUT WARRANTY OF ANY KIND, EXPRESS OR
 IMPLIED, INCLUDING BUT NOT LIMITED TO THE WARRANTIES OF MERCHANTABILITY,
 FITNESS FOR A PARTICULAR PURPOSE AND NONINFRINGEMENT. IN NO EVENT SHALL THE
 AUTHORS OR COPYRIGHT HOLDERS BE LIABLE FOR ANY CLAIM, DAMAGES OR OTHER
 LIABILITY, WHETHER IN AN ACTION OF CONTRACT, TORT OR OTHERWISE, ARISING FROM,
 OUT OF OR IN CONNECTION WITH THE SOFTWARE OR THE USE OR OTHER DEALINGS IN
 THE SOFTWARE.
 ================================================================================================
 */

#ifndef _MPU6050_H_
#define _MPU6050_H_

#ifdef __cplusplus
extern "C" {
#endif

/* Includes */
#include <stdint.h>
#include <stdbool.h>
#include "stm32f10x.h"

#define MPU6050_ADDRESS_AD0_LOW     0x68 // address pin low (GND), default for InvenSense evaluation board
#define MPU6050_ADDRESS_AD0_HIGH    0x69 // address pin high (VCC)
#define MPU6050_DEFAULT_ADDRESS     (MPU6050_ADDRESS_AD0_LOW<<1)

#define MPU6050_RA_XG_OFFS_TC       0x00 //[7] PWR_MODE, [6:1] XG_OFFS_TC, [0] OTP_BNK_VLD
#define MPU6050_RA_YG_OFFS_TC       0x01 //[7] PWR_MODE, [6:1] YG_OFFS_TC, [0] OTP_BNK_VLD
#define MPU6050_RA_ZG_OFFS_TC       0x02 //[7] PWR_MODE, [6:1] ZG_OFFS_TC, [0] OTP_BNK_VLD
#define MPU6050_RA_X_FINE_GAIN      0x03 //[7:0] X_FINE_GAIN
#define MPU6050_RA_Y_FINE_GAIN      0x04 //[7:0] Y_FINE_GAIN
#define MPU6050_RA_Z_FINE_GAIN      0x05 //[7:0] Z_FINE_GAIN
#define MPU6050_RA_XA_OFFS_H        0x06 //[15:0] XA_OFFS
#define MPU6050_RA_XA_OFFS_L_TC     0x07
#define MPU6050_RA_YA_OFFS_H        0x08 //[15:0] YA_OFFS
#define MPU6050_RA_YA_OFFS_L_TC     0x09
#define MPU6050_RA_ZA_OFFS_H        0x0A //[15:0] ZA_OFFS
#define MPU6050_RA_ZA_OFFS_L_TC     0x0B
#define MPU6050_RA_XG_OFFS_USRH     0x13 //[15:0] XG_OFFS_USR
#define MPU6050_RA_XG_OFFS_USRL     0x14
#define MPU6050_RA_YG_OFFS_USRH     0x15 //[15:0] YG_OFFS_USR
#define MPU6050_RA_YG_OFFS_USRL     0x16
#define MPU6050_RA_ZG_OFFS_USRH     0x17 //[15:0] ZG_OFFS_USR
#define MPU6050_RA_ZG_OFFS_USRL     0x18
#define MPU6050_RA_SMPLRT_DIV       0x19
#define MPU6050_RA_CONFIG           0x1A
#define MPU6050_RA_GYRO_CONFIG      0x1B
#define MPU6050_RA_ACCEL_CONFIG     0x1C
#define MPU6050_RA_FF_THR           0x1D
#define MPU6050_RA_FF_DUR           0x1E
#define MPU6050_RA_MOT_THR          0x1F
#define MPU6050_RA_MOT_DUR          0x20
#define MPU6050_RA_ZRMOT_THR        0x21
#define MPU6050_RA_ZRMOT_DUR        0x22
#define MPU6050_RA_FIFO_EN          0x23
#define MPU6050_RA_I2C_MST_CTRL     0x24
#define MPU6050_RA_I2C_SLV0_ADDR    0x25
#define MPU6050_RA_I2C_SLV0_REG     0x26
#define MPU6050_RA_I2C_SLV0_CTRL    0x27
#define MPU6050_RA_I2C_SLV1_ADDR    0x28
#define MPU6050_RA_I2C_SLV1_REG     0x29
#define MPU6050_RA_I2C_SLV1_CTRL    0x2A
#define MPU6050_RA_I2C_SLV2_ADDR    0x2B
#define MPU6050_RA_I2C_SLV2_REG     0x2C
#define MPU6050_RA_I2C_SLV2_CTRL    0x2D
#define MPU6050_RA_I2C_SLV3_ADDR    0x2E
#define MPU6050_RA_I2C_SLV3_REG     0x2F
#define MPU6050_RA_I2C_SLV3_CTRL    0x30
#define MPU6050_RA_I2C_SLV4_ADDR    0x31
#define MPU6050_RA_I2C_SLV4_REG     0x32
#define MPU6050_RA_I2C_SLV4_DO      0x33
#define MPU6050_RA_I2C_SLV4_CTRL    0x34
#define MPU6050_RA_I2C_SLV4_DI      0x35
#define MPU6050_RA_I2C_MST_STATUS   0x36
#define MPU6050_RA_INT_PIN_CFG      0x37
#define MPU6050_RA_INT_ENABLE       0x38
#define MPU6050_RA_DMP_INT_STATUS   0x39
#define MPU6050_RA_INT_STATUS       0x3A
#define MPU6050_RA_ACCEL_XOUT_H     0x3B
#define MPU6050_RA_ACCEL_XOUT_L     0x3C
#define MPU6050_RA_ACCEL_YOUT_H     0x3D
#define MPU6050_RA_ACCEL_YOUT_L     0x3E
#define MPU6050_RA_ACCEL_ZOUT_H     0x3F
#define MPU6050_RA_ACCEL_ZOUT_L     0x40
#define MPU6050_RA_TEMP_OUT_H       0x41
#define MPU6050_RA_TEMP_OUT_L       0x42
#define MPU6050_RA_GYRO_XOUT_H      0x43
#define MPU6050_RA_GYRO_XOUT_L      0x44
#define MPU6050_RA_GYRO_YOUT_H      0x45
#define MPU6050_RA_GYRO_YOUT_L      0x46
#define MPU6050_RA_GYRO_ZOUT_H      0x47
#define MPU6050_RA_GYRO_ZOUT_L      0x48
#define MPU6050_RA_EXT_SENS_DATA_00 0x49
#define MPU6050_RA_EXT_SENS_DATA_01 0x4A
#define MPU6050_RA_EXT_SENS_DATA_02 0x4B
#define MPU6050_RA_EXT_SENS_DATA_03 0x4C
#define MPU6050_RA_EXT_SENS_DATA_04 0x4D
#define MPU6050_RA_EXT_SENS_DATA_05 0x4E
#define MPU6050_RA_EXT_SENS_DATA_06 0x4F
#define MPU6050_RA_EXT_SENS_DATA_07 0x50
#define MPU6050_RA_EXT_SENS_DATA_08 0x51
#define MPU6050_RA_EXT_SENS_DATA_09 0x52
#define MPU6050_RA_EXT_SENS_DATA_10 0x53
#define MPU6050_RA_EXT_SENS_DATA_11 0x54
#define MPU6050_RA_EXT_SENS_DATA_12 0x55
#define MPU6050_RA_EXT_SENS_DATA_13 0x56
#define MPU6050_RA_EXT_SENS_DATA_14 0x57
#define MPU6050_RA_EXT_SENS_DATA_15 0x58
#define MPU6050_RA_EXT_SENS_DATA_16 0x59
#define MPU6050_RA_EXT_SENS_DATA_17 0x5A
#define MPU6050_RA_EXT_SENS_DATA_18 0x5B
#define MPU6050_RA_EXT_SENS_DATA_19 0x5C
#define MPU6050_RA_EXT_SENS_DATA_20 0x5D
#define MPU6050_RA_EXT_SENS_DATA_21 0x5E
#define MPU6050_RA_EXT_SENS_DATA_22 0x5F
#define MPU6050_RA_EXT_SENS_DATA_23 0x60
#define MPU6050_RA_MOT_DETECT_STATUS    0x61
#define MPU6050_RA_I2C_SLV0_DO      0x63
#define MPU6050_RA_I2C_SLV1_DO      0x64
#define MPU6050_RA_I2C_SLV2_DO      0x65
#define MPU6050_RA_I2C_SLV3_DO      0x66
#define MPU6050_RA_I2C_MST_DELAY_CTRL   0x67
#define MPU6050_RA_SIGNAL_PATH_RESET    0x68
#define MPU6050_RA_MOT_DETECT_CTRL      0x69
#define MPU6050_RA_USER_CTRL        0x6A
#define MPU6050_RA_PWR_MGMT_1       0x6B
#define MPU6050_RA_PWR_MGMT_2       0x6C
#define MPU6050_RA_BANK_SEL         0x6D
#define MPU6050_RA_MEM_START_ADDR   0x6E
#define MPU6050_RA_MEM_R_W          0x6F
#define MPU6050_RA_DMP_CFG_1        0x70
#define MPU6050_RA_DMP_CFG_2        0x71
#define MPU6050_RA_FIFO_COUNTH      0x72
#define MPU6050_RA_FIFO_COUNTL      0x73
#define MPU6050_RA_FIFO_R_W         0x74
#define MPU6050_RA_WHO_AM_I         0x75

#define MPU6050_TC_PWR_MODE_BIT     7
#define MPU6050_TC_OFFSET_BIT       6
#define MPU6050_TC_OFFSET_LENGTH    6
#define MPU6050_TC_OTP_BNK_VLD_BIT  0

#define MPU6050_VDDIO_LEVEL_VLOGIC  0
#define MPU6050_VDDIO_LEVEL_VDD     1

#define MPU6050_CFG_EXT_SYNC_SET_BIT    5
#define MPU6050_CFG_EXT_SYNC_SET_LENGTH 3
#define MPU6050_CFG_DLPF_CFG_BIT    2
#define MPU6050_CFG_DLPF_CFG_LENGTH 3
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

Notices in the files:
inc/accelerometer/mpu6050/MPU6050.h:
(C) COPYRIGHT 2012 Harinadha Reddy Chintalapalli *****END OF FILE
